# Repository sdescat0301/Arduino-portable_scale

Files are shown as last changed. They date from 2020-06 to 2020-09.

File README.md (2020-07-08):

# 用Arduino实现的电子手提秤项目

这是一个用Arduino Nano与外接电路、传感器实现的电子手提秤项目  

 **正在完善中！**

## 用到的物品

+ Arduino Nano [购买链接](https://item.taobao.com/item.htm?id=557545360329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)
+ 0.96寸OLED I2C 12864显示屏 [购买链接](https://item.taobao.com/item.htm?spm=a230r.1.14.34.66de2171HhS42s&id=528232253877&ns=1&abbucket=13#detail)
+ ADS1115模数转换器芯片 [购买链接](https://item.szlcsc.com/38573.html)
+ INA333仪用放大器 [购买链接](https://item.szlcsc.com/20159.html)
+ L78M05贴片三端稳压管 [购买链接](https://item.szlcsc.com/59107.html)
+ ICL7660电压转换芯片 [购买链接](https://item.szlcsc.com/8358.html)
+ 悬臂梁式力传感器 [购买链接](https://item.taobao.com/item.htm?spm=a230r.1.14.21.150378972D1pdC&id=569898995913&ns=1&abbucket=13#detail)
+ 自行设计的电路板与用到的贴片电容、电阻及连接用导线（具体请见“电路设计”文件夹中的README）
+ 自行设计的内部骨架与外壳
+ 9V电池一个

## 图片

+ 原理图  

+ PCB 2D图  
PCB 2D图.png
+ PCB 3D图  
PCB 3D图.png

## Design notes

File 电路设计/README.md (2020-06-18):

# 关于自制电路板

## 焊接接口

在设计阶段我们设计了接插件，但接插件体积太大，所以我们决定直接在焊盘上飞线。（P4除外）

+ **P1**  1：接电池+9V；2：GND
+ **P2**  2：-5V，接传感器负输入；1：GND
+ **P3**  1：接传感器正输出；2：接传感器负输出
+ **P4**  1：接屏幕SDA；2：接屏幕SCL；3：接屏幕供电（+5V）

## 元件封装

+ 二极管  
D1：SMA  
D2，D3：0805（LED，颜色任意）  
+ 电容  
C1，C2：100uF，B型（3528）钽电容  
C3，C6：1uF，1206电容  
C4，C5：10uF，1206电容
+ 电阻  
R1，R2：4.7KΩ，1206电阻  
R3：100Ω，1206电阻  
R4，R5：10kΩ，1206电阻
+ 排座  
实际上只需要P4用来插屏幕，其他的直接在焊盘上飞线即可。  
P4为1*4排座（针脚间距2.54mm）  
+ IC  
VR1：L78M05，封装为TO-252-2  
U1：ICL7660，封装为SOIC-8  
U2：INA333，封装为VSSOP-8  
U3：ADS1115，封装为MSOP-10

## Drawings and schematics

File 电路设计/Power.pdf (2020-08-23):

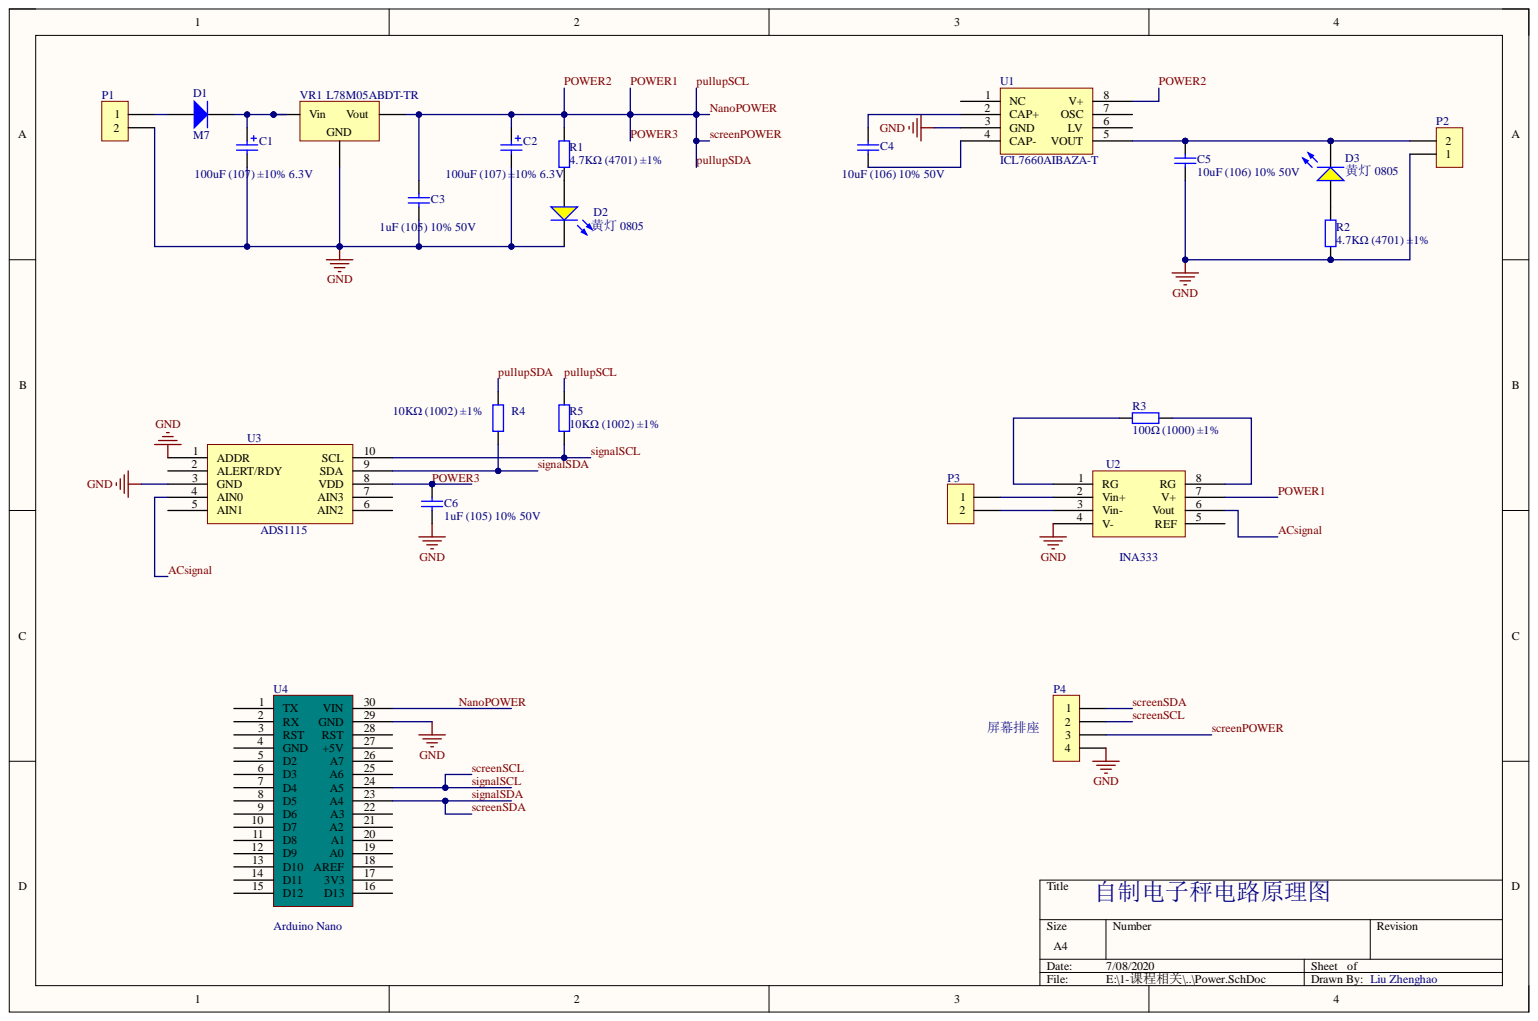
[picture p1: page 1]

GND 3

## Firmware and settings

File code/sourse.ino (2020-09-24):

#include "U8glib.h"
#include "Adafruit_ADS1015.h"
#include "Wire.h"

U8GLIB_SSD1306_128X64 u8g(U8G_I2C_OPT_NONE|U8G_I2C_OPT_DEV_0);	  // 屏幕型号，I2C / TWI

String mess_in_Kg = "weight(kg):";
String mess_in_lb = "weight(lb):";

Adafruit_ADS1115 ads(0x48);    //声明一个ads对象，设置模块地址
float base_voltage = 0.0;   //空载电压，用于调零
float Voltage = 0.0;    //存储检测到的电压值
float true_voltage = 0.0;   //存储由于重物改变的电压值，也就是理论上的电压值
float Weight = 0.0;    //存储计算得到的质量#include <U8glib.h>
#include <Wire.h>

U8GLIB_SSD1306_128X64 u8g(U8G_I2C_OPT_NONE|U8G_I2C_OPT_DEV_0);	  // 屏幕型号，I2C / TWI

String mess_in_Kg = "weight(kg):";
String mess_in_lb = "weight(lb):";

float base_voltage = 0.0;   //空载电压，用于调零
float Voltage = 0.0;    //存储检测到的电压值
float true_voltage = 0.0;   //存储由于重物改变的电压值，也就是理论上的电压值
float Weight = 0.0;    //存储计算得到的质量

void draw(float Weight)   //函数：在显示屏上输出,单位为kg
{
    u8g.setFont(u8g_font_fur17r);    //设置第一行字体
    u8g.setPrintPos(5,20);    //设置第一行输出位置
    u8g.print(mess_in_Kg);    //输出第一行"weight(kg):"
    u8g.setFont(u8g_font_fur30n);    //设置第二行字体
    u8g.setPrintPos(20,60);    //设置第二行输出单位
    u8g.print(Weight);    //输出第二行：重量
}

void setup()
{
    Serial.begin(9600);    //开始串口通信，设置波特率为9600
    pinMode(A7,INPUT);
    
    base_voltage = (float)analogRead(A7)*5.00/4096;  //读数

}

void loop() 
{
    int16_t adc = analogRead(A7);    //读取挂上重物时力传感器的信号
    Serial.println(adc);
    Voltage = (float)adc * 5.00/4096;    //计算挂上重物之后的电压值
    true_voltage = Voltage - base_voltage;    //计算由于挂上重物而增加的电压值
    Weight = true_voltage * 80 * 500 / 390;    //计算质量
    Weight = ( (float)( (int)( (Weight+0.005)*100 ) ) )/100;    //取重量小数点后两位

    u8g.firstPage();  
    do {
        draw(Weight);
    } while( u8g.nextPage() );    //输出质量（单位为kg）
  
    delay(30);
}

void draw(int Weight)   //函数：在显示屏上输出,单位为kg
{
    u8g.setFont(u8g_font_fur17r);    //设置第一行字体
    u8g.setPrintPos(20,10);    //设置第一行输出位置
    u8g.print(mess_in_Kg);    //输出第一行"weight(kg):"
    u8g.setFont(u8g_font_fur30n);    //设置第二行字体
    u8g.setPrintPos(20,50);    //设置第二行输出单位
    u8g.print(Weight);    //输出第二行：重量
}

void setup()
{
    Serial.begin(9600);    //开始串口通信，设置波特率为9600
    ads.begin();    //开始读数
    ads.setGain(GAIN_TWOTHIRDS);    // 设置增益为2/3x，输入电压的范围为6.144V，实际输入0-5V，输出数字为0-26667
    
    uint16_t base_adc = ads.readADC_SingleEnded(0);    //读取空载时力传感器的信号（系统误差）
    base_voltage = (float)base_adc * 0.003;    //计算由于系统误差带来的空载电压
}

void loop() 
{
    uint16_t adc = ads.readADC_SingleEnded(0);    //读取挂上重物时力传感器的信号
    Voltage = (float)adc * 0.003;    //计算挂上重物之后的电压值

    true_voltage = Voltage - base_voltage;    //计算由于挂上重物而增加的电压值
    Weight = true_voltage * 4;    //计算质量
    Weight = ( (float)( (int)( (Weight+0.005)*100 ) ) )/100;    //取重量小数点后两位

    u8g.firstPage();  
    do {
        draw(Weight);
    } while( u8g.nextPage() );    //输出质量（单位为kg）
  
    delay(30);
}

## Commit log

2020-06-05 commit1-add sourse&header
    源代码和目前用到的头文件
2020-07-07 增加力传感器购买链接
2020-08-23 <add>元件列表
    [元件列表.xlsx]
